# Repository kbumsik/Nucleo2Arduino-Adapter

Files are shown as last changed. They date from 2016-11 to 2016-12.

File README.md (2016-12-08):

Universal Shields Adapter for STM32 Nucleo 64 boards
====================================================

Universal Adapter for Nucleo 64 boards that supports various expansion boards
including:

* STM32 Nucleo pinsas a mother
* Arduino shields, **including ICSP(SPI) pins**
* TI BoosterPack (LaunchPad) 40-pin
* 2 x Atmel Xplained Pro expansion boards

Image (v0.5 test board)
=======================
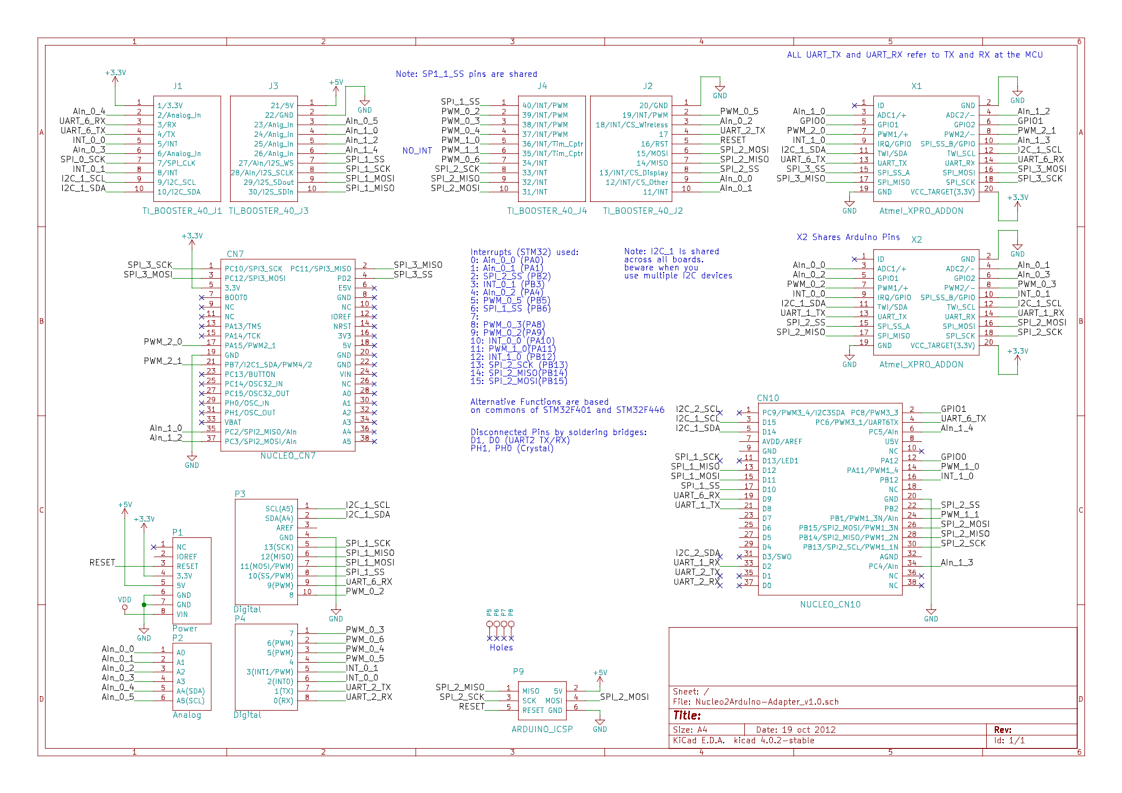
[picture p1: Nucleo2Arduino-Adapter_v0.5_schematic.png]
schematic Schematic


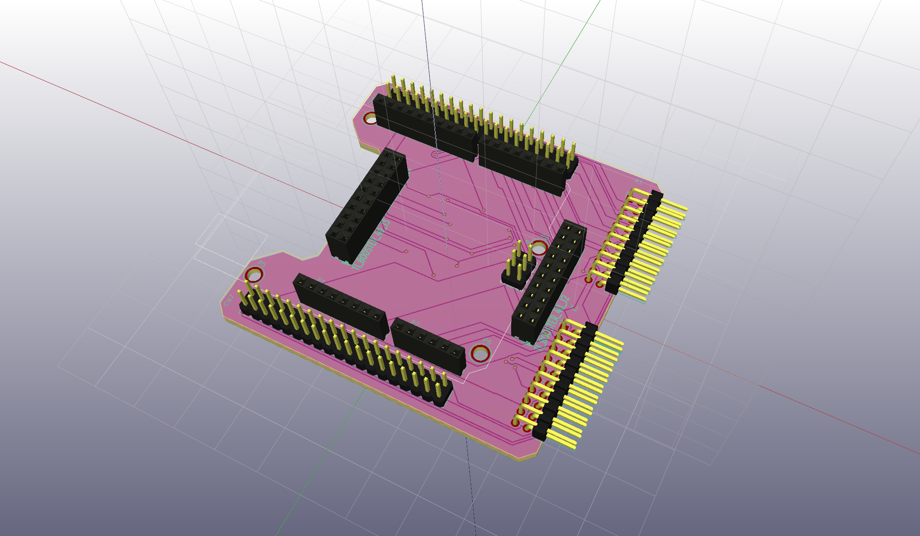
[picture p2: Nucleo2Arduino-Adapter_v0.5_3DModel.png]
3D_model 3D Model


Why?
====

STM32 Nucleo boards are awesome development boards to start a microcontroller
project. However, ther is a caveat: it does not have variaous expansion boards.
Even though Nucleo boards have Arduino-compatible header pins, a problem still
aries here:

> *Nucleo boards do not have Arduino ICSP/SPI pins!*

Absence of ICSP pins losses supports for various arduino shields. So I decided
to make an adapter shield to support for Arduino shields. Making this adapter I
also added some headers for other companies expansion boards like TI's BoosterPack.

I believe this adapter will remove nasty wiring jobs when you work with expansion boards.

Tested expansion boards
=======================
Although this adapter will support most of Arduino shields and expansion boards
we are always unexpected things making it not to supports some boards. So I attach
tested expansion boards here

* ATWINC1500 Xplained Pro

Please email me (kbumsik@gmail.com) or PR if you tested other boards.

External Libraries Used
=======================
I used the following libraries:

* [KiCad Library](https://github.com/KiCad/kicad-library/tree/master/template)

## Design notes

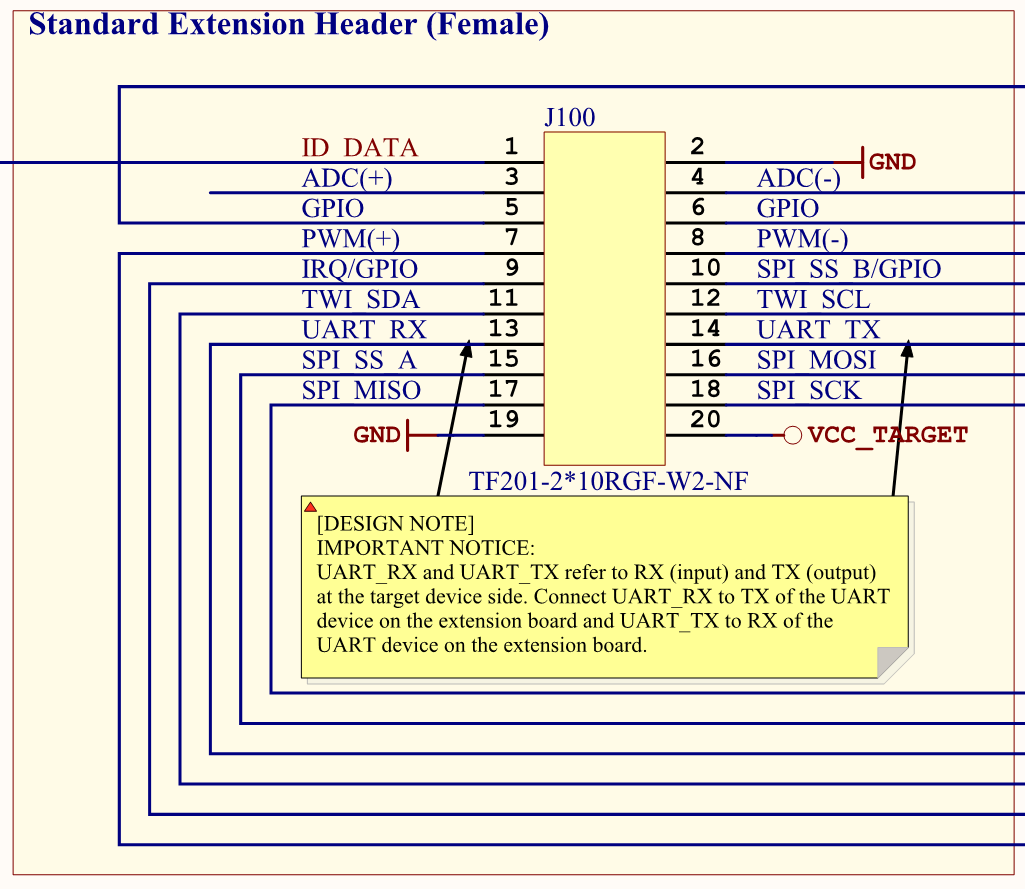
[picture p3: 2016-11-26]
reference/atmel_xplained_pro_1.png

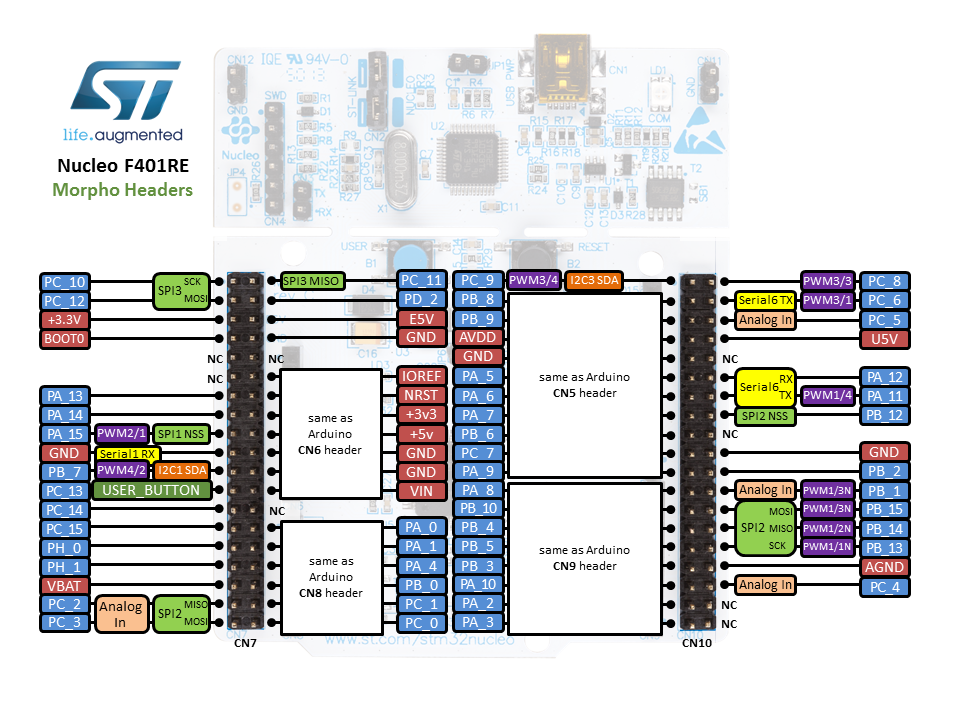
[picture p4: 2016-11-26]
reference/nucleo_f401_zio.png

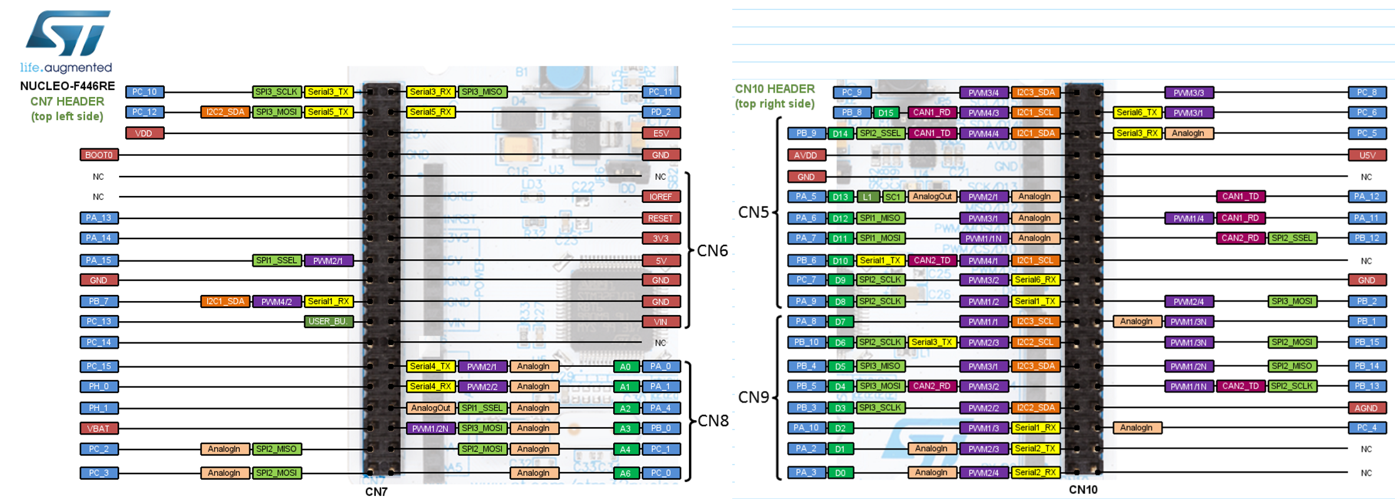
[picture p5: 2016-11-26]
reference/nucleo_f446_zio.png

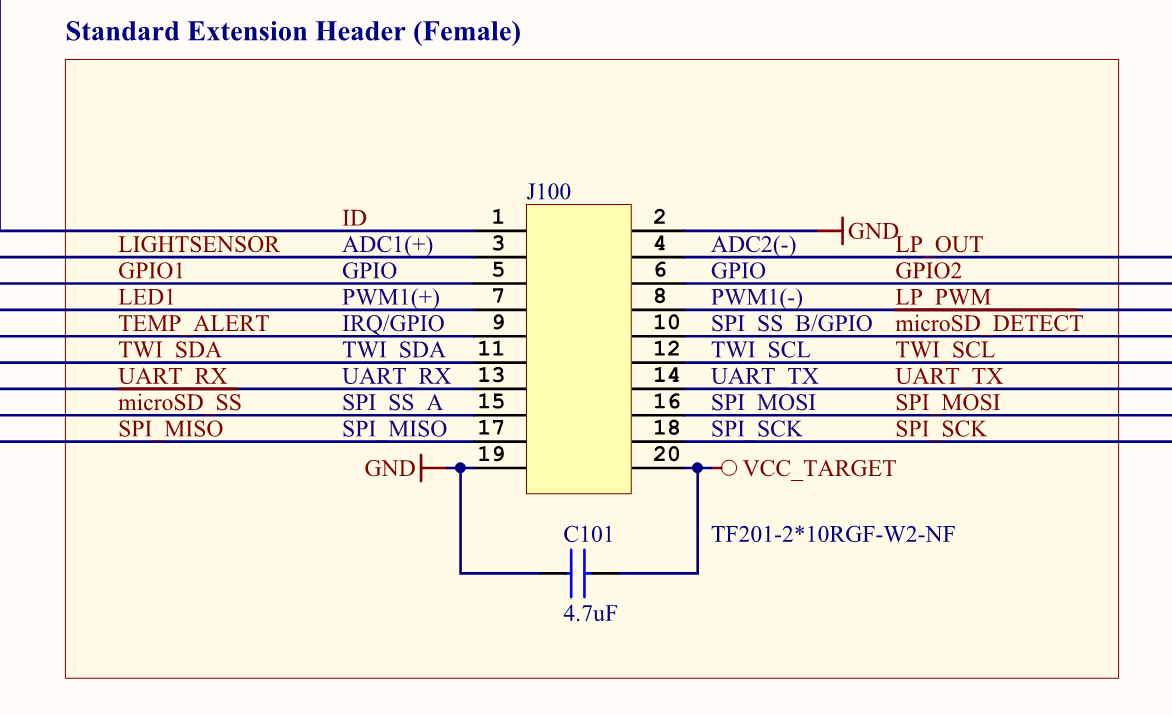
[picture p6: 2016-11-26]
reference/atmel_xplained_pro_2.png

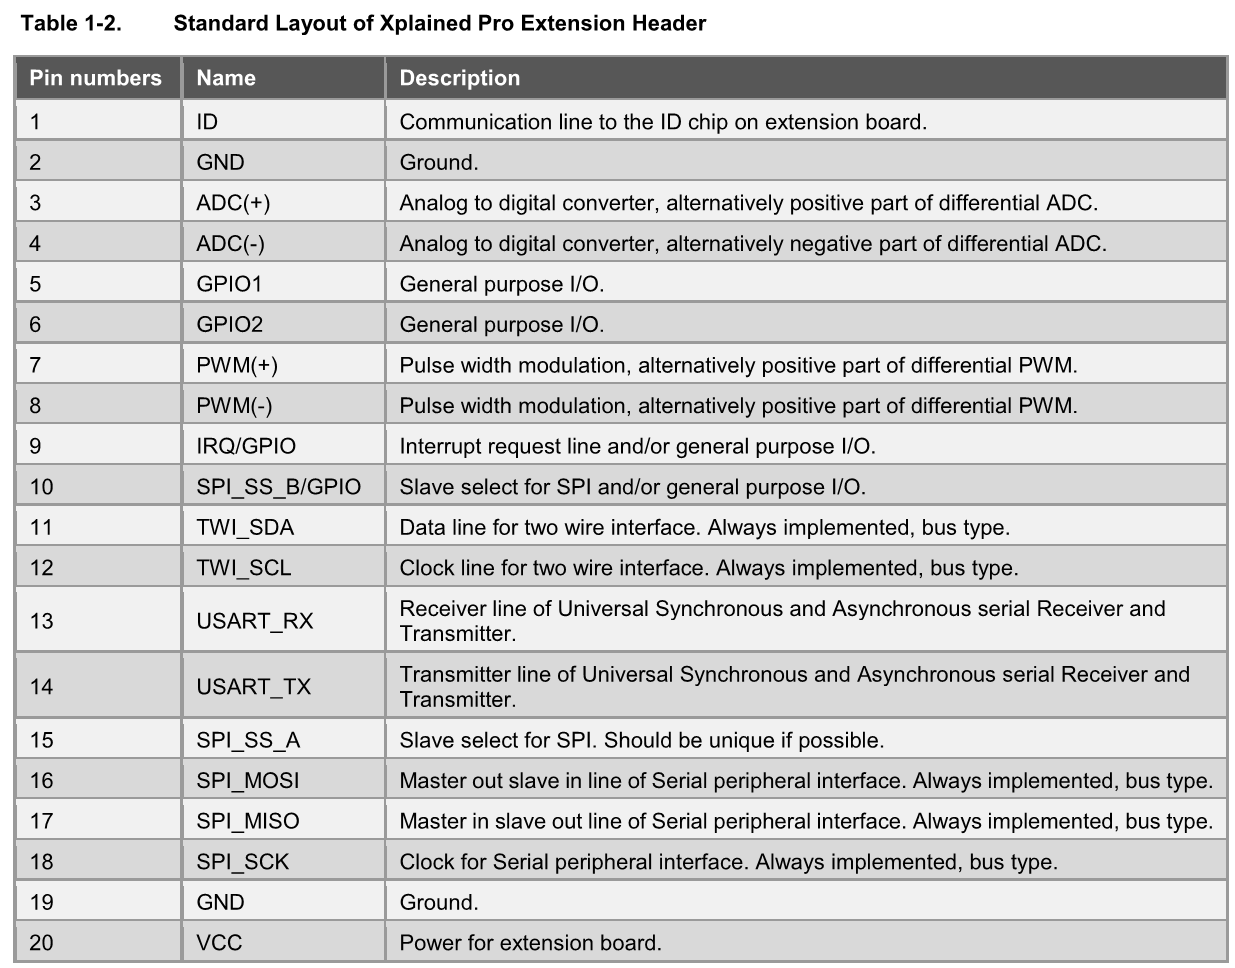
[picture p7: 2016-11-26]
reference/atmel_xplained_pro_table.png

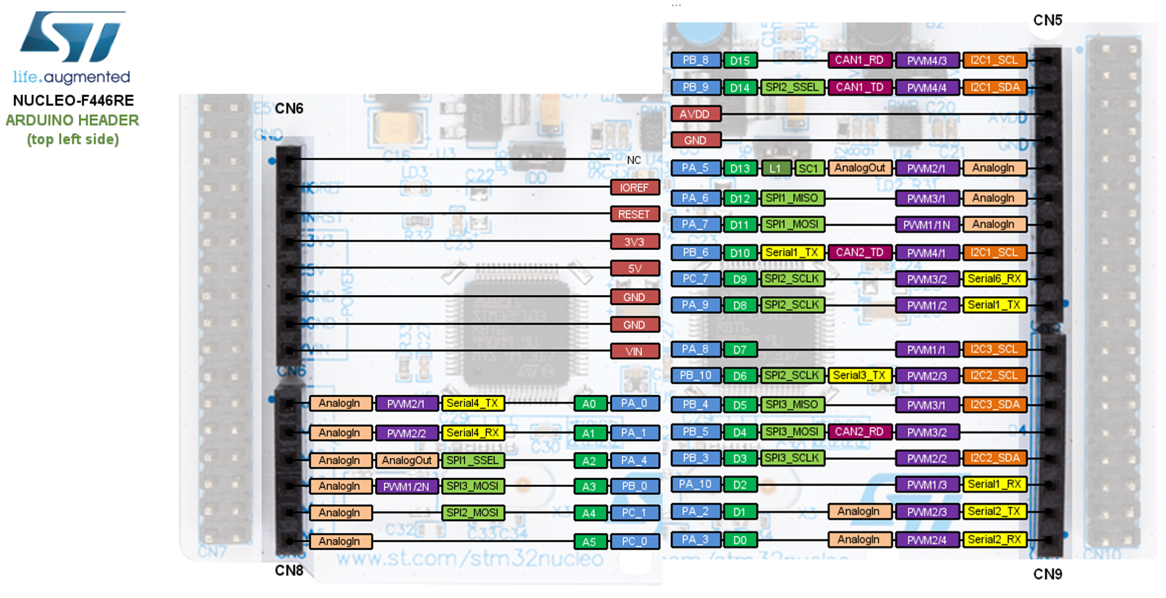
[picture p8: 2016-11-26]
reference/nucleo_f446_arduino.png

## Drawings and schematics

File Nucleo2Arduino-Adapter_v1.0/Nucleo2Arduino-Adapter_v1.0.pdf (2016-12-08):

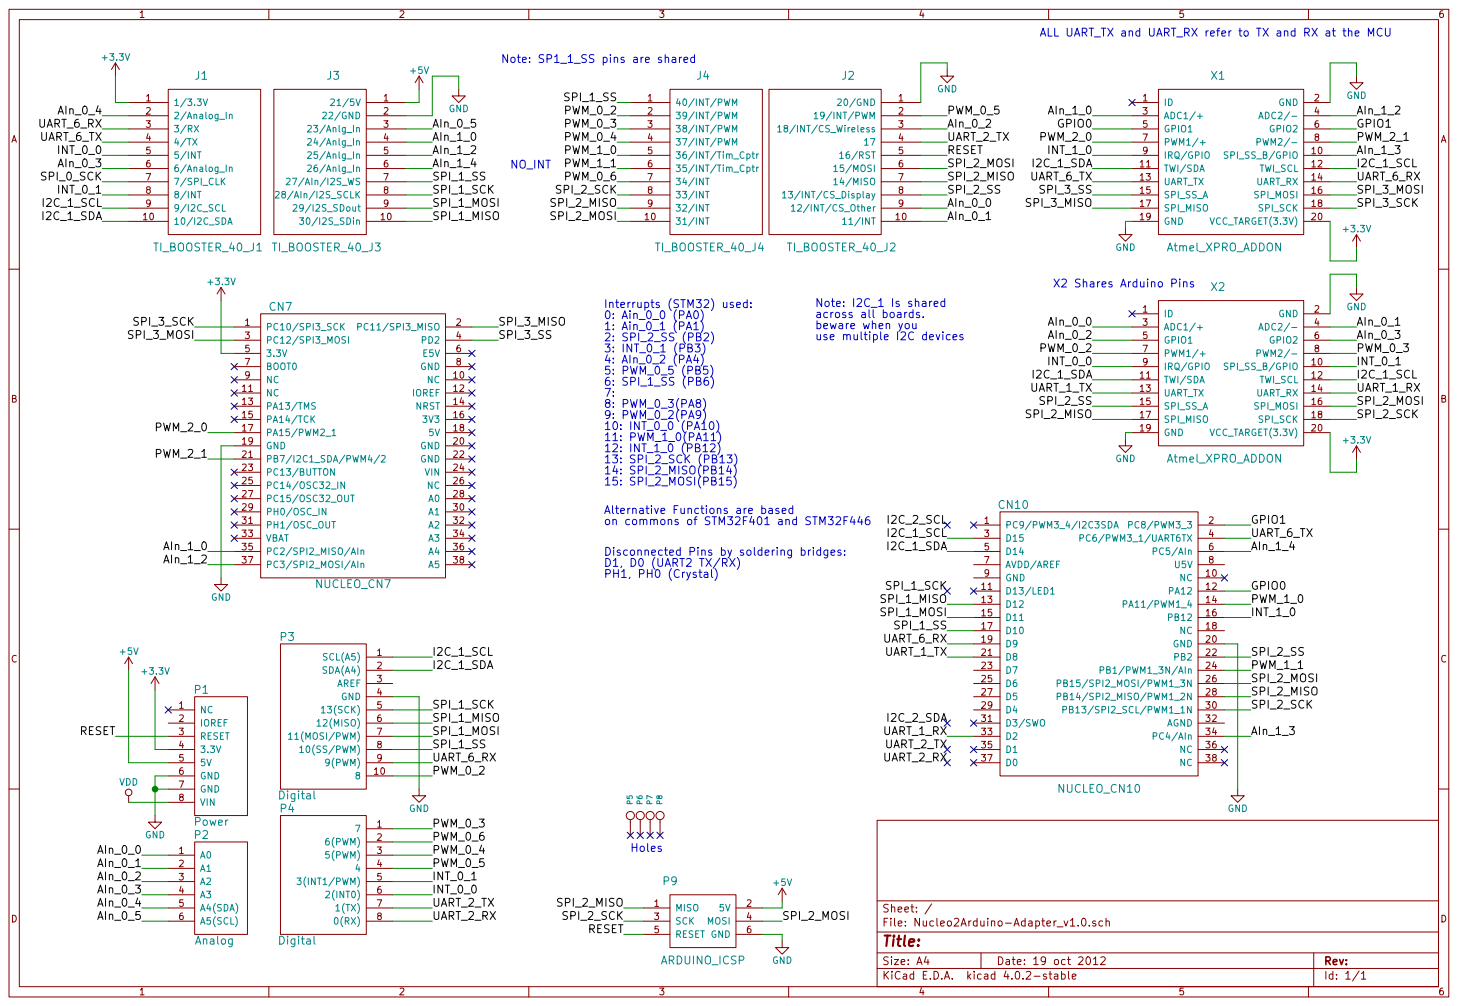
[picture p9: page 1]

ALL UART_TX and UART_RX refer to TX and RX at the MCU

Note: SP1_1_SS pins are shared

GND GND X2 Shares Arduino Pins

Note: I2C_1 Is shared
across all boards. beware when you
use multiple I2C devices

NUCLEO_CN10 Alternative Functions are based
on commons of STM32F401 and STM32F446

Disconnected Pins by soldering bridges:
D1, D0 (UART2 TX/RX)
PH1, PH0 (Crystal)

NUCLEO_CN7
File: Nucleo2Arduino-Adapter_v1.0.sch Sheet: / NC 1

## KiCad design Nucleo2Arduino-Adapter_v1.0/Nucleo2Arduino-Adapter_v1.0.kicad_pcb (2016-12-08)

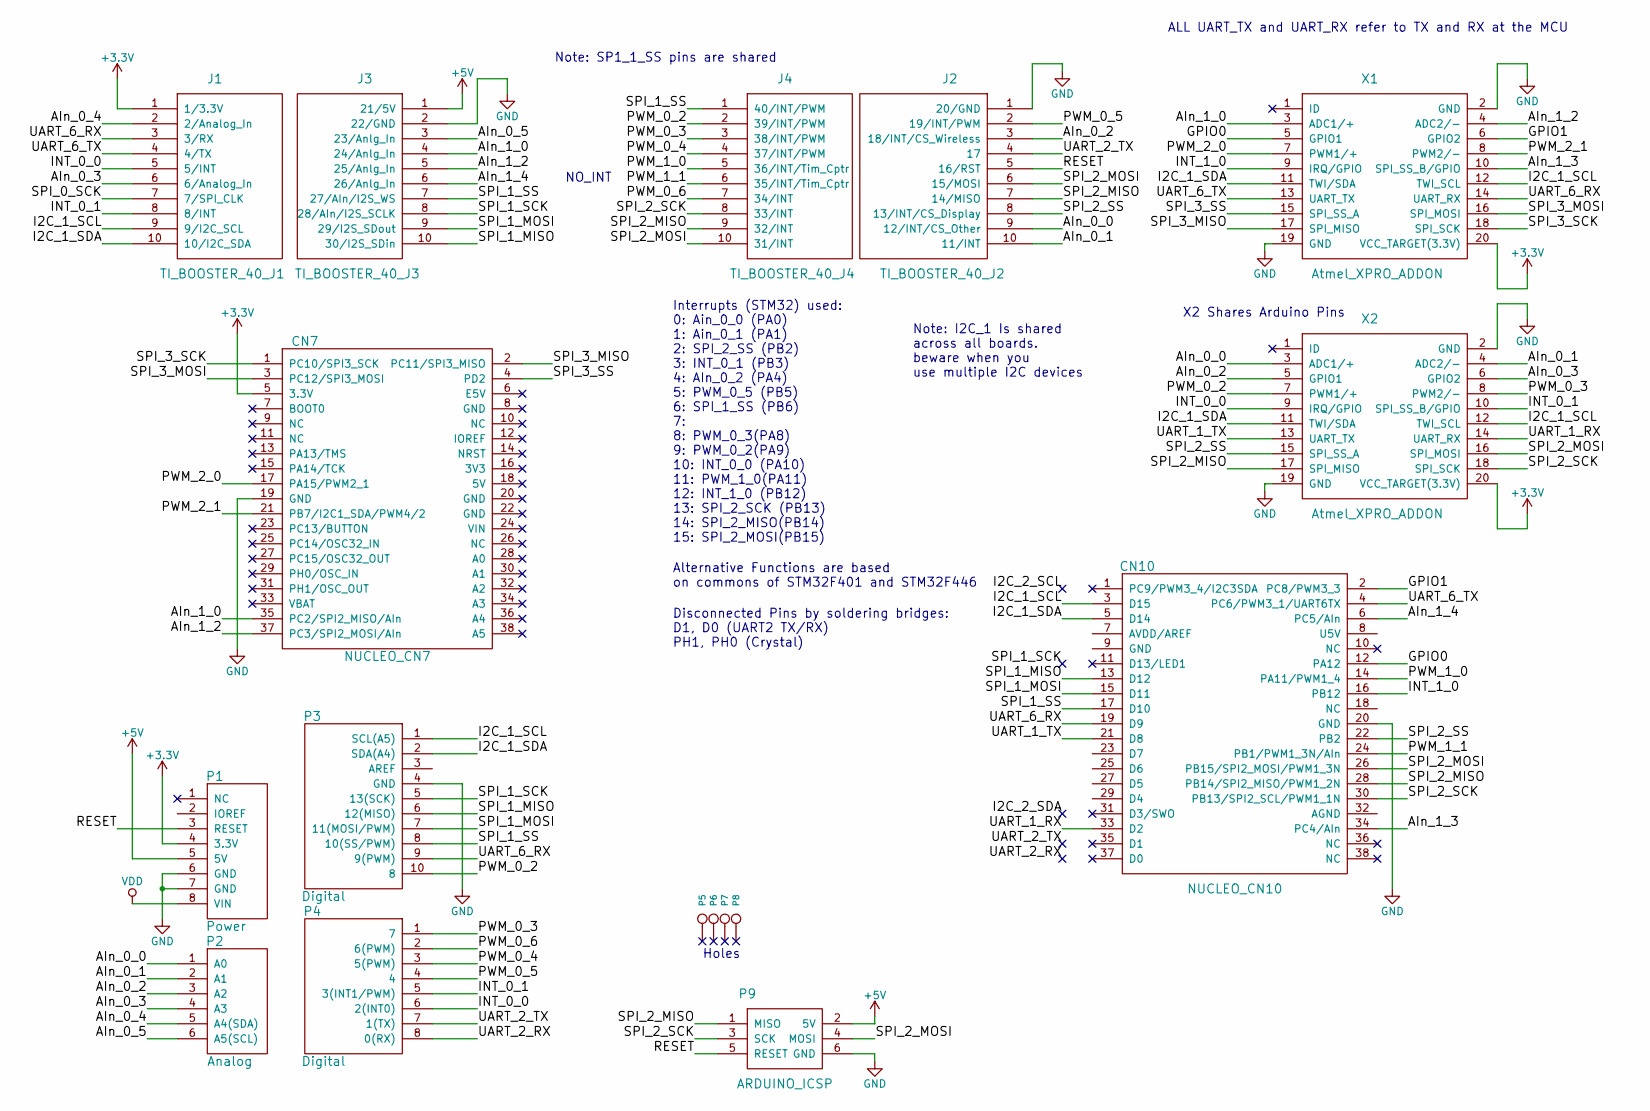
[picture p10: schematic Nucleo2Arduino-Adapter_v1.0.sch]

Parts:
CN7: NUCLEO_CN7; Pin_Header_Straight_2x19
CN10: NUCLEO_CN10; Pin_Header_Straight_2x19
J1: TI_BOOSTER_40_J1; SIL-10
J2: TI_BOOSTER_40_J2; SIL-10
J3: TI_BOOSTER_40_J3; SIL-10
J4: TI_BOOSTER_40_J4; SIL-10
P1: Power; Socket_Strip_Arduino_1x08
P2: Analog; Socket_Strip_Arduino_1x06
P3: Digital; Socket_Strip_Arduino_1x10
P4: Digital; Socket_Strip_Arduino_1x08
P5, P6, P7, P8: CONN_1; Arduino_1pin
P9: ARDUINO_ICSP; Pin_Header_Straight_2x03
X1, X2: Atmel_XPRO_ADDON; Pin_Header_Angled_2x10

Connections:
+3V3: CN7.5 (3.3V), J1.1 (1/3.3V), P1.4 (3.3V), X1.20 (VCC_TARGET(3.3V)), X2.20 (VCC_TARGET(3.3V))
+5V: J3.1 (21/5V), P1.5 (5V), P9.2 (5V)
/AIn_0_0: J2.9 (12/INT/CS_Other), P2.1 (A0), X2.3 (ADC1/+)
/AIn_0_1: J2.10 (11/INT), P2.2 (A1), X2.4 (ADC2/-)
/AIn_0_2: J2.3 (18/INT/CS_Wireless), P2.3 (A2), X2.5 (GPIO1)
/AIn_0_3: J1.6 (6/Analog_In), P2.4 (A3), X2.6 (GPIO2)
/AIn_0_4: J1.2 (2/Analog_In), P2.5 (A4(SDA))
/AIn_0_5: J3.3 (23/Anlg_In), P2.6 (A5(SCL))
/AIn_1_0: CN7.35 (PC2/SPI2_MISO/AIn), J3.4 (24/Anlg_In), X1.3 (ADC1/+)
/AIn_1_2: CN7.37 (PC3/SPI2_MOSI/AIn), J3.5 (25/Anlg_In), X1.4 (ADC2/-)
/AIn_1_3: CN10.34 (PC4/AIn), X1.10 (SPI_SS_B/GPIO)
/AIn_1_4: CN10.6 (PC5/AIn), J3.6 (26/Anlg_In)
/GPIO0: CN10.12 (PA12), X1.5 (GPIO1)
/GPIO1: CN10.2 (PC8/PWM3_3), X1.6 (GPIO2)
/I2C_1_SCL: CN10.3 (D15), J1.9 (9/I2C_SCL), P3.1 (SCL(A5)), X1.12 (TWI_SCL), X2.12 (TWI_SCL)
/I2C_1_SDA: CN10.5 (D14), J1.10 (10/I2C_SDA), P3.2 (SDA(A4)), X1.11 (TWI/SDA), X2.11 (TWI/SDA)
/INT_0_0: J1.5 (5/INT), P4.6 (2(INT0)), X2.9 (IRQ/GPIO)
/INT_0_1: J1.8 (8/INT), P4.5 (3(INT1/PWM)), X2.10 (SPI_SS_B/GPIO)
/INT_1_0: CN10.16 (PB12), X1.9 (IRQ/GPIO)
/PWM_0_2: J4.2 (39/INT/PWM), P3.10 (8), X2.7 (PWM1/+)
/PWM_0_3: J4.3 (38/INT/PWM), P4.1 (7), X2.8 (PWM2/-)
/PWM_0_4: J4.4 (37/INT/PWM), P4.3 (5(PWM))
/PWM_0_5: J2.2 (19/INT/PWM), P4.4
/PWM_0_6: J4.7 (34/INT), P4.2 (6(PWM))
/PWM_1_0: CN10.14 (PA11/PWM1_4), J4.5 (36/INT/Tim_Cptr)
/PWM_1_1: CN10.24 (PB1/PWM1_3N/AIn), J4.6 (35/INT/Tim_Cptr)
/PWM_2_0: CN7.17 (PA15/PWM2_1), X1.7 (PWM1/+)
/PWM_2_1: CN7.21 (PB7/I2C1_SDA/PWM4/2), X1.8 (PWM2/-)
/RESET: J2.5 (16/RST), P1.3 (RESET), P9.5 (RESET)
/SPI_0_SCK: J1.7 (7/SPI_CLK)
/SPI_1_MISO: CN10.13 (D12), J3.10 (30/I2S_SDin), P3.6 (12(MISO))
/SPI_1_MOSI: CN10.15 (D11), J3.9 (29/I2S_SDout), P3.7 (11(MOSI/PWM))
/SPI_1_SCK: J3.8 (28/AIn/I2S_SCLK), P3.5 (13(SCK))
/SPI_1_SS: CN10.17 (D10), J3.7 (27/AIn/I2S_WS), J4.1 (40/INT/PWM), P3.8 (10(SS/PWM))
/SPI_2_MISO: CN10.28 (PB14/SPI2_MISO/PWM1_2N), J2.7 (14/MISO), J4.9 (32/INT), P9.1 (MISO), X2.17 (SPI_MISO)
/SPI_2_MOSI: CN10.26 (PB15/SPI2_MOSI/PWM1_3N), J2.6 (15/MOSI), J4.10 (31/INT), P9.4 (MOSI), X2.16 (SPI_MOSI)
/SPI_2_SCK: CN10.30 (PB13/SPI2_SCL/PWM1_1N), J4.8 (33/INT), P9.3 (SCK), X2.18 (SPI_SCK)
/SPI_2_SS: CN10.22 (PB2), J2.8 (13/INT/CS_Display), X2.15 (SPI_SS_A)
/SPI_3_MISO: CN7.2 (PC11/SPI3_MISO), X1.17 (SPI_MISO)
/SPI_3_MOSI: CN7.3 (PC12/SPI3_MOSI), X1.16 (SPI_MOSI)
/SPI_3_SCK: CN7.1 (PC10/SPI3_SCK), X1.18 (SPI_SCK)
/SPI_3_SS: CN7.4 (PD2), X1.15 (SPI_SS_A)
/UART_1_RX: CN10.33 (D2), X2.14 (UART_RX)
/UART_1_TX: CN10.21 (D8), X2.13 (UART_TX)
/UART_2_RX: P4.8 (0(RX))
/UART_2_TX: J2.4 (17), P4.7 (1(TX))
/UART_6_RX: CN10.19 (D9), J1.3 (3/RX), P3.9 (9(PWM)), X1.14 (UART_RX)
/UART_6_TX: CN10.4 (PC6/PWM3_1/UART6TX), J1.4 (4/TX), X1.13 (UART_TX)
GND: CN7.19 (GND), CN10.20 (GND), J2.1 (20/GND), J3.2 (22/GND), P1.6 (GND), P1.7 (GND), P3.4 (GND), P9.6 (GND), X1.2 (GND), X1.19 (GND), X2.2 (GND), X2.19 (GND)
VDD: P1.8 (VIN)

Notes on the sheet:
Holes
Alternative Functions are based on commons of STM32F401 and STM32F446
ALL UART_TX and UART_RX refer to TX and RX at the MCU
X2 Shares Arduino Pins
Disconnected Pins by soldering bridges: D1, D0 (UART2 TX/RX) PH1, PH0 (Crystal)
Interrupts (STM32) used: 0: Ain_0_0 (PA0) 1: Ain_0_1 (PA1) 2: SPI_2_SS (PB2) 3: INT_0_1 (PB3) 4: AIn_0_2 (PA4) 5: PWM_0_5 (PB5) 6: SPI_1_SS (PB6) 7: 8: PWM_0_3(PA8) 9: PWM_0_2(PA9) 10: INT_0_0 (PA10) 11: PWM_1_0(PA11) 12: INT_1_0 (PB12) 13: SPI_2_SCK (PB13) 14: SPI_2_MISO(PB14) 15: SPI_2_MOSI(PB15)
NO_INT
Note: SP1_1_SS pins are shared
Note: I2C_1 Is shared across all boards. beware when you use multiple I2C devices

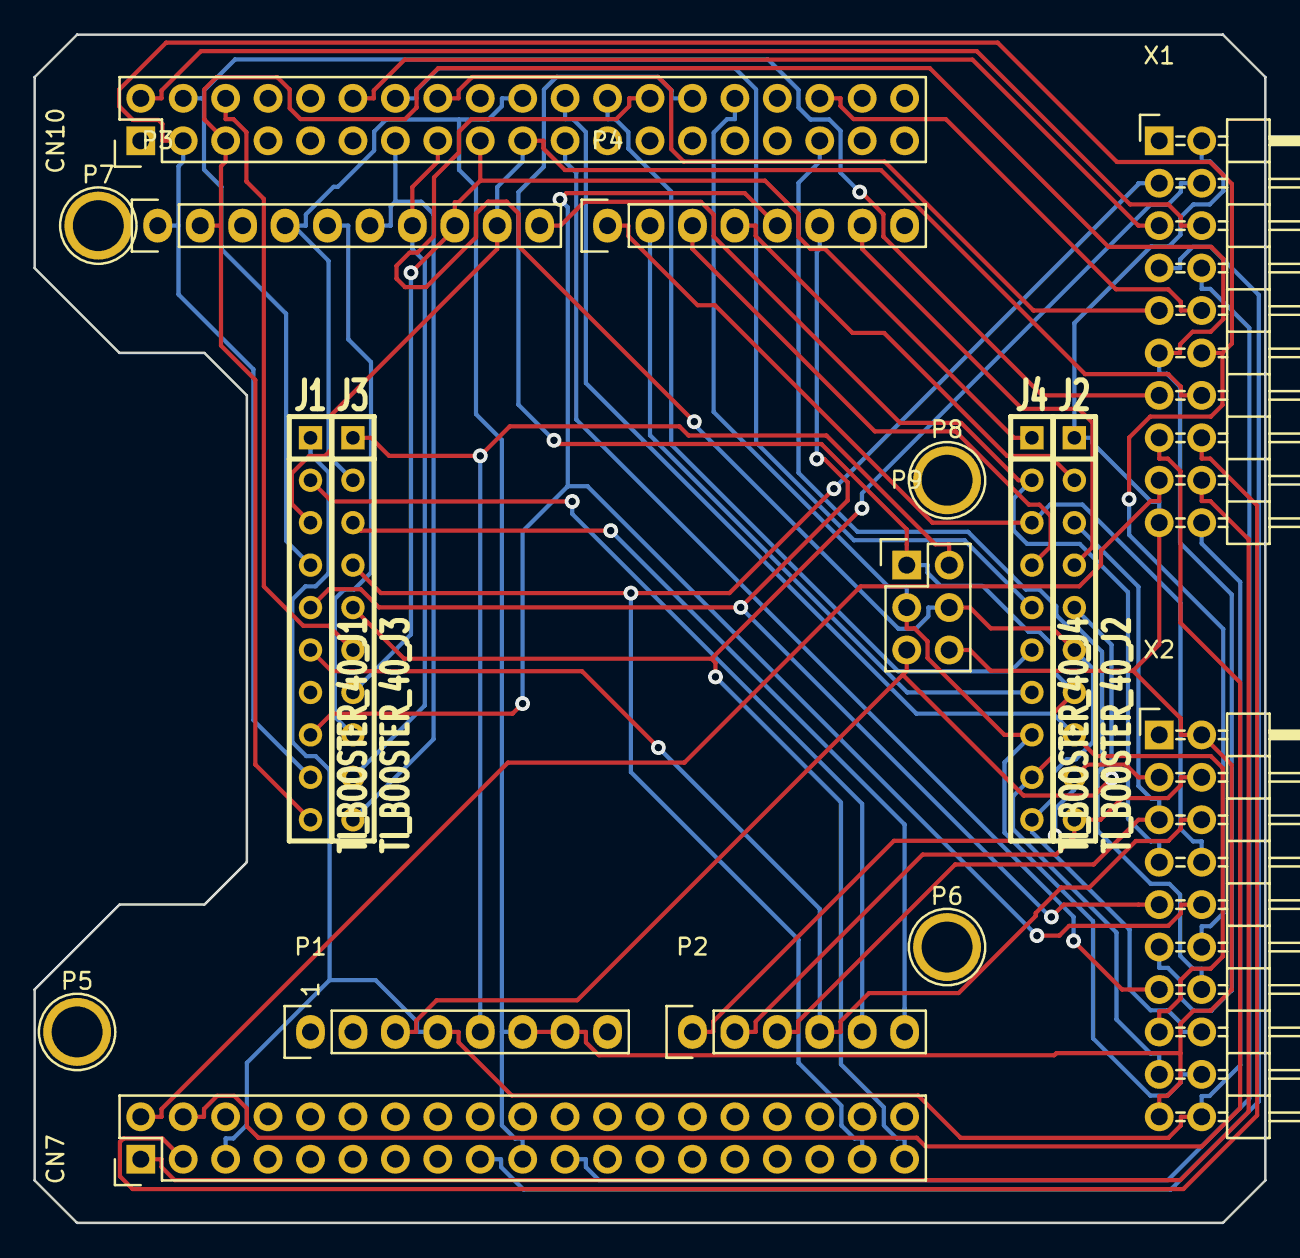
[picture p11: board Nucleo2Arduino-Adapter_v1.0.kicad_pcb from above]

Board: 2 copper layers, 73.7 x 71.1 mm, 17 parts (0 on the bottom side), 47 nets.

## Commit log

2016-11-26 added Arduino and TI boosterpack
    [Nucleo2Arduino-Adapter_v1.0.kicad_pcb, Nucleo2Arduino-Adapter_v1.0.sch]
2016-11-29 fixed Arduino pin symbol
    [Nucleo2Arduino-Adapter_v1.0.sch]
2016-11-29 Added ICSP header, Fixed Ardino/BSTPCK Symbols, Added connection
    [Nucleo2Arduino-Adapter_v1.0.kicad_pcb, Nucleo2Arduino-Adapter_v1.0.sch]
2016-11-30 added Nucleo Zio and Atmel XPro Header symbol
    [Nucleo2Arduino-Adapter_v1.0.kicad_pcb, Nucleo2Arduino-Adapter_v1.0.sch]
2016-12-06 First draft of connection. Completed PCB pin position
    [Nucleo2Arduino-Adapter_v1.0.kicad_pcb, Nucleo2Arduino-Adapter_v1.0.sch]
2016-12-07 Connections and PCB footprint completed. Needs routing
    [Nucleo2Arduino-Adapter_v1.0.dsn, Nucleo2Arduino-Adapter_v1.0.kicad_pcb, Nucleo2Arduino-Adapter_v1.0.sch]
2016-12-08 Generated gerber files. Placed a first order
    [Nucleo2Arduino-Adapter_v1.0-B.Cu.gbl, Nucleo2Arduino-Adapter_v1.0-B.Mask.gbs, Nucleo2Arduino-Adapter_v1.0-B.Paste.gbp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]
2016-12-08 Updated README and pdf files
    [Nucleo2Arduino-Adapter_v1.0.kicad_pcb]
